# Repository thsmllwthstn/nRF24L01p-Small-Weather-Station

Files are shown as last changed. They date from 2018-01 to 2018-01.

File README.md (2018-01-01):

# Small Weather Station with nRF24L01+

For any nRF24L01+ project!

Vcc: 3.3V - 15V

### Description
Start a nRF24L01+ sensor network or expand your existing projects with this Small Weather Station!
This comes with easy to use example codes for Arduino and Raspberry Pi!

This station measures and sends:

 -Temperature
 
 -Humidity
 
 -Lightintensity

To achieve this the station uses three different sensors:

 -DS18B20: Digital temperature sensor
 
 -DHT11: Basic temperature and humidity sensor
 
 -LDR: Measures lightintensity

### What do you need?
You will need a Small Weather Station and your own nRF24L01+ receiver.
You can buy the Small Weather Station in the link below:

--ebay link

Or you can build your own station, you can find the schematics and source code in the link below:
https://github.com/thsmllwthstn/nRF24L01p-Small-Weather-Station/tree/master/station/station_basic

In the link below you will find an easy example code written for Arduino and Python 3 for receiving data from the station:
https://github.com/thsmllwthstn/nRF24L01p-Small-Weather-Station/tree/master/receiver

Simply copy and paste this code and you are ready to retreive data from the station!

### How does it work?
Power the Vin pin with 3V3 - 15V.

As soon as the onboard LED blinks 2 times in a row the station starts sending the data.

Use the example code to receive the data.

It sends the data every 5 seconds.

You can change the stations settings by pressing the button. The LED will go ON. The station is now in receiving mode.
There are 4 settings you can change:

 -Timer (rate at which the station sends the data in seconds)
 
 -Tranceive address
 
 -Receive address
 
 -Frequency

The example code explains in detail how to change these settings.

### Add a waterproof digital temperature sensor!
The station comes with 3 additional pins for connecting a waterproof DS18B20 temperature sensor.
Solder the Vcc, data and ground pins from the temperature sensor to the 3V3, data and GND pin from the station.
Once connected the station detects the presence of the added DS18B20 sensor.
The station will now send the standard readings with the added DS18B20 sensor!

### Programmable Small Weather Station?
Do you want full access to all the settings or use the station to control any other 3V3 circuit?
This is possible with a USBASP programmer and the programmable small weather station: 

--ebay link

Or you can build your own programmable station, you can find the schematics and source code in the link below:
https://github.com/thsmllwthstn/nRF24L01p-Small-Weather-Station/tree/master/station/station_basic_with_programmer

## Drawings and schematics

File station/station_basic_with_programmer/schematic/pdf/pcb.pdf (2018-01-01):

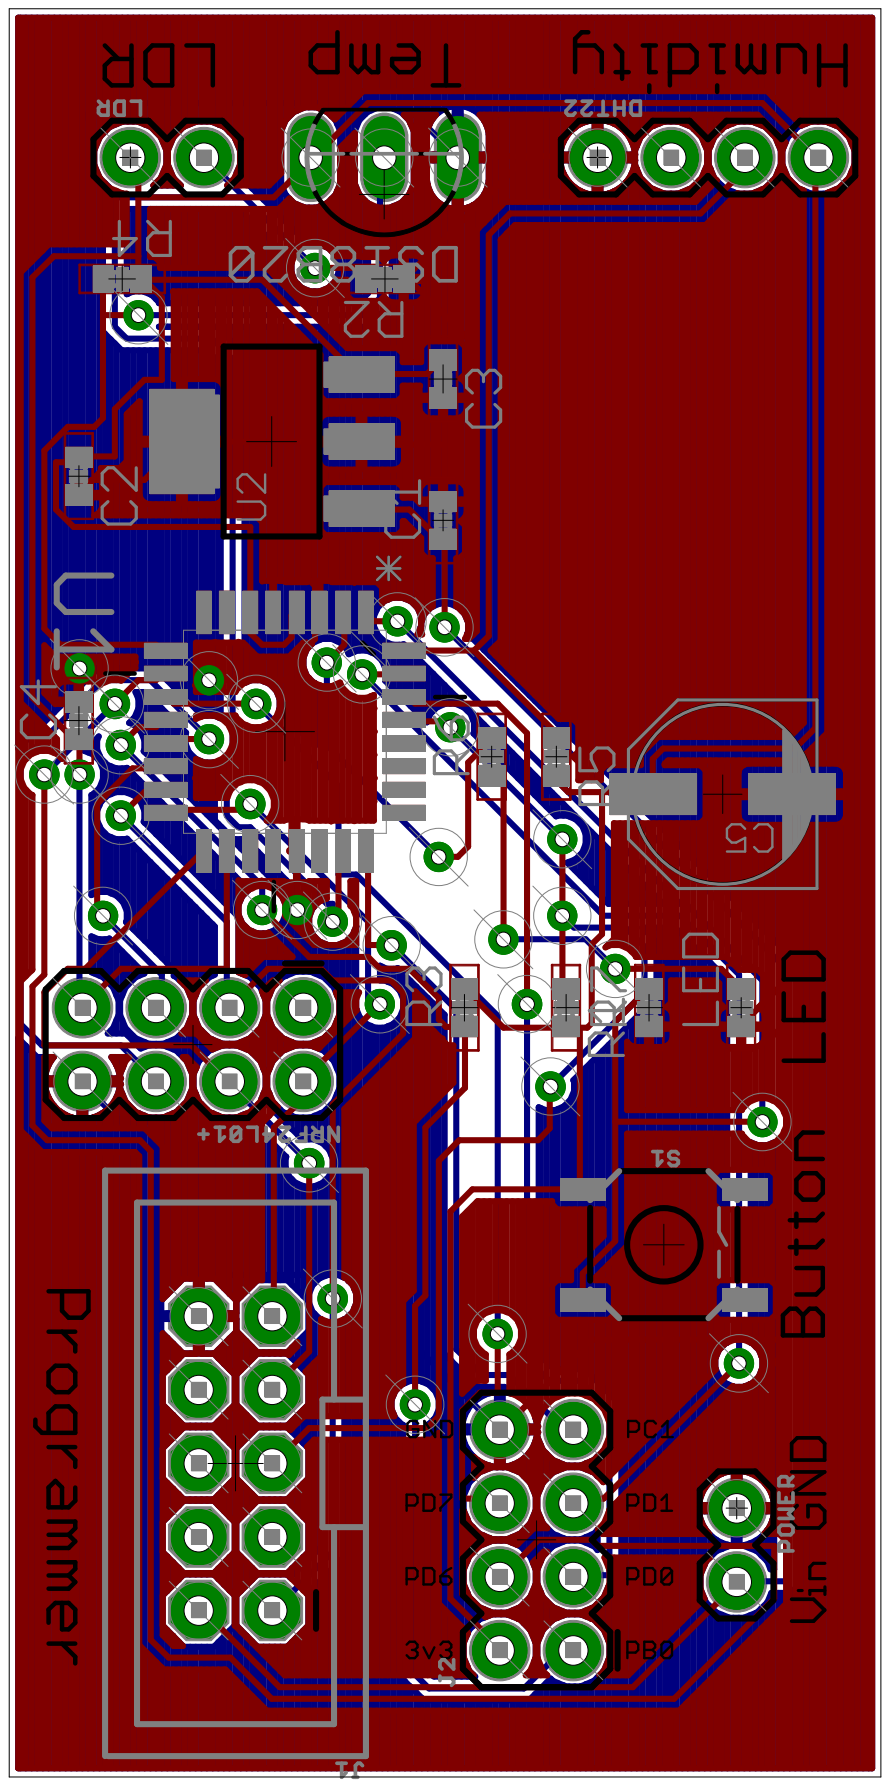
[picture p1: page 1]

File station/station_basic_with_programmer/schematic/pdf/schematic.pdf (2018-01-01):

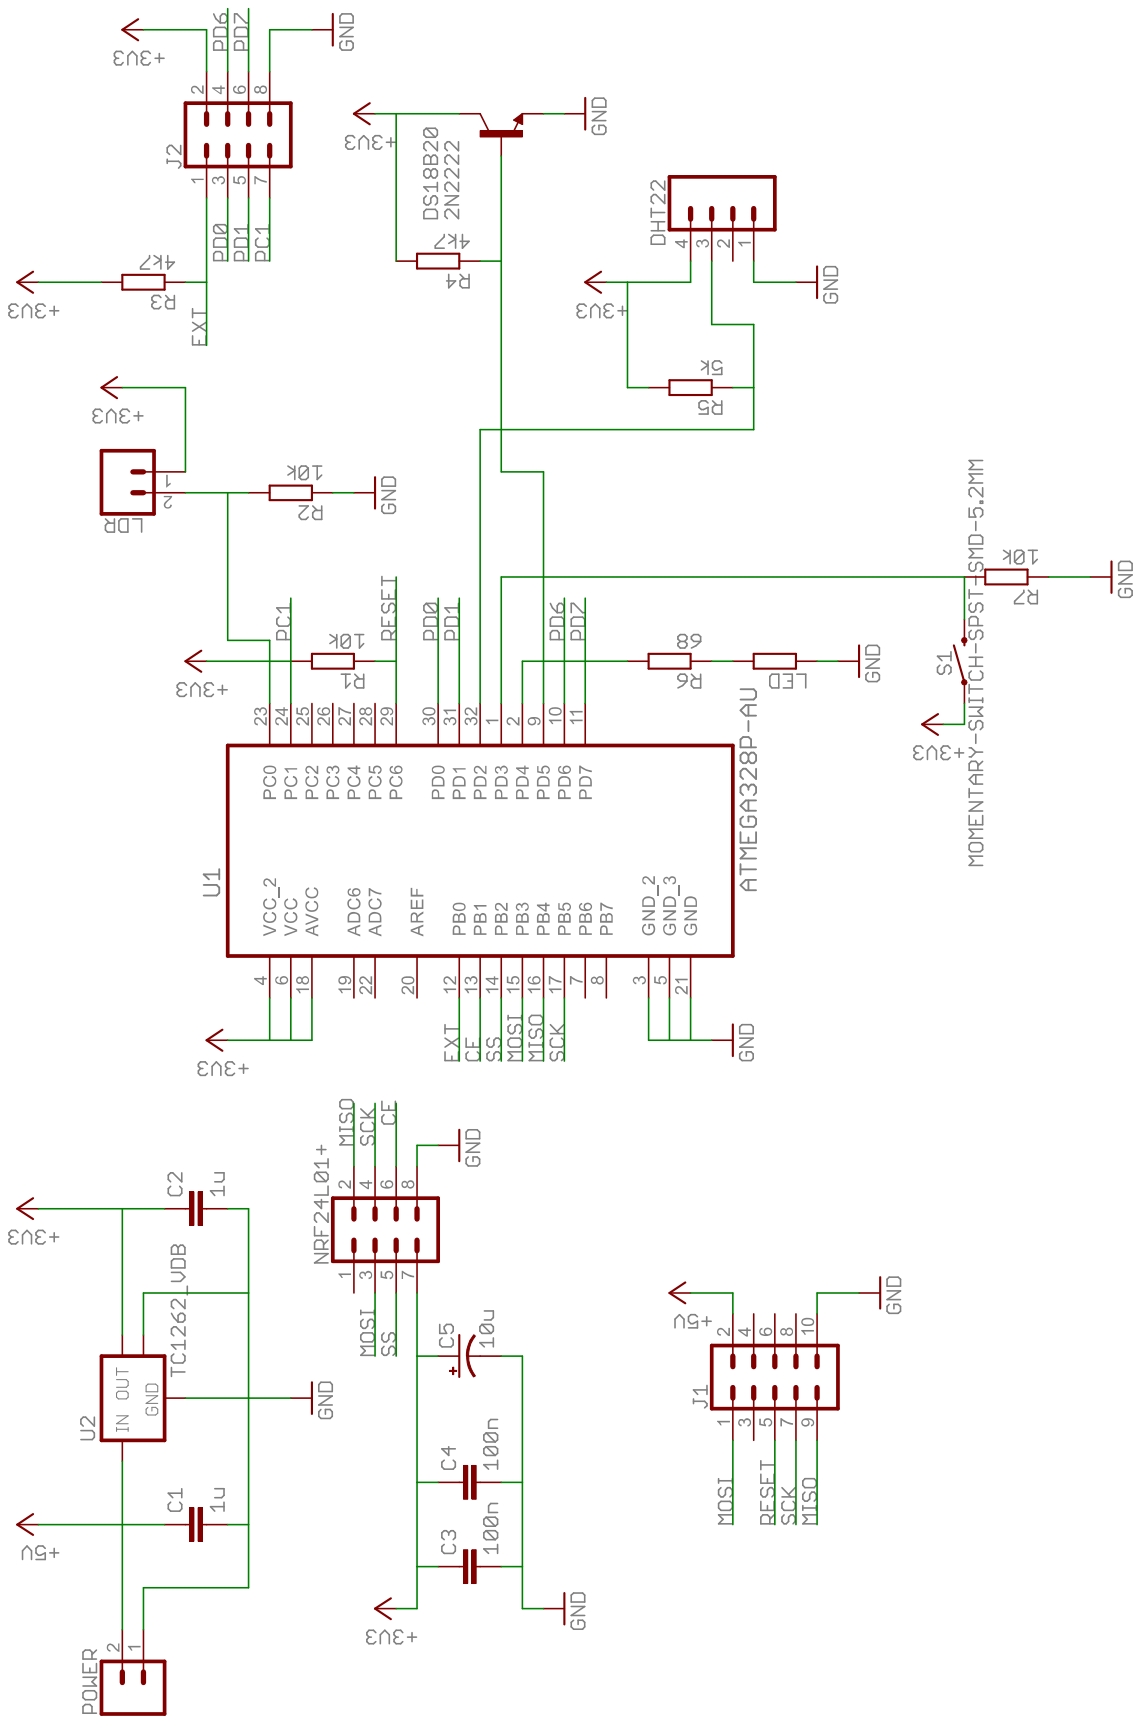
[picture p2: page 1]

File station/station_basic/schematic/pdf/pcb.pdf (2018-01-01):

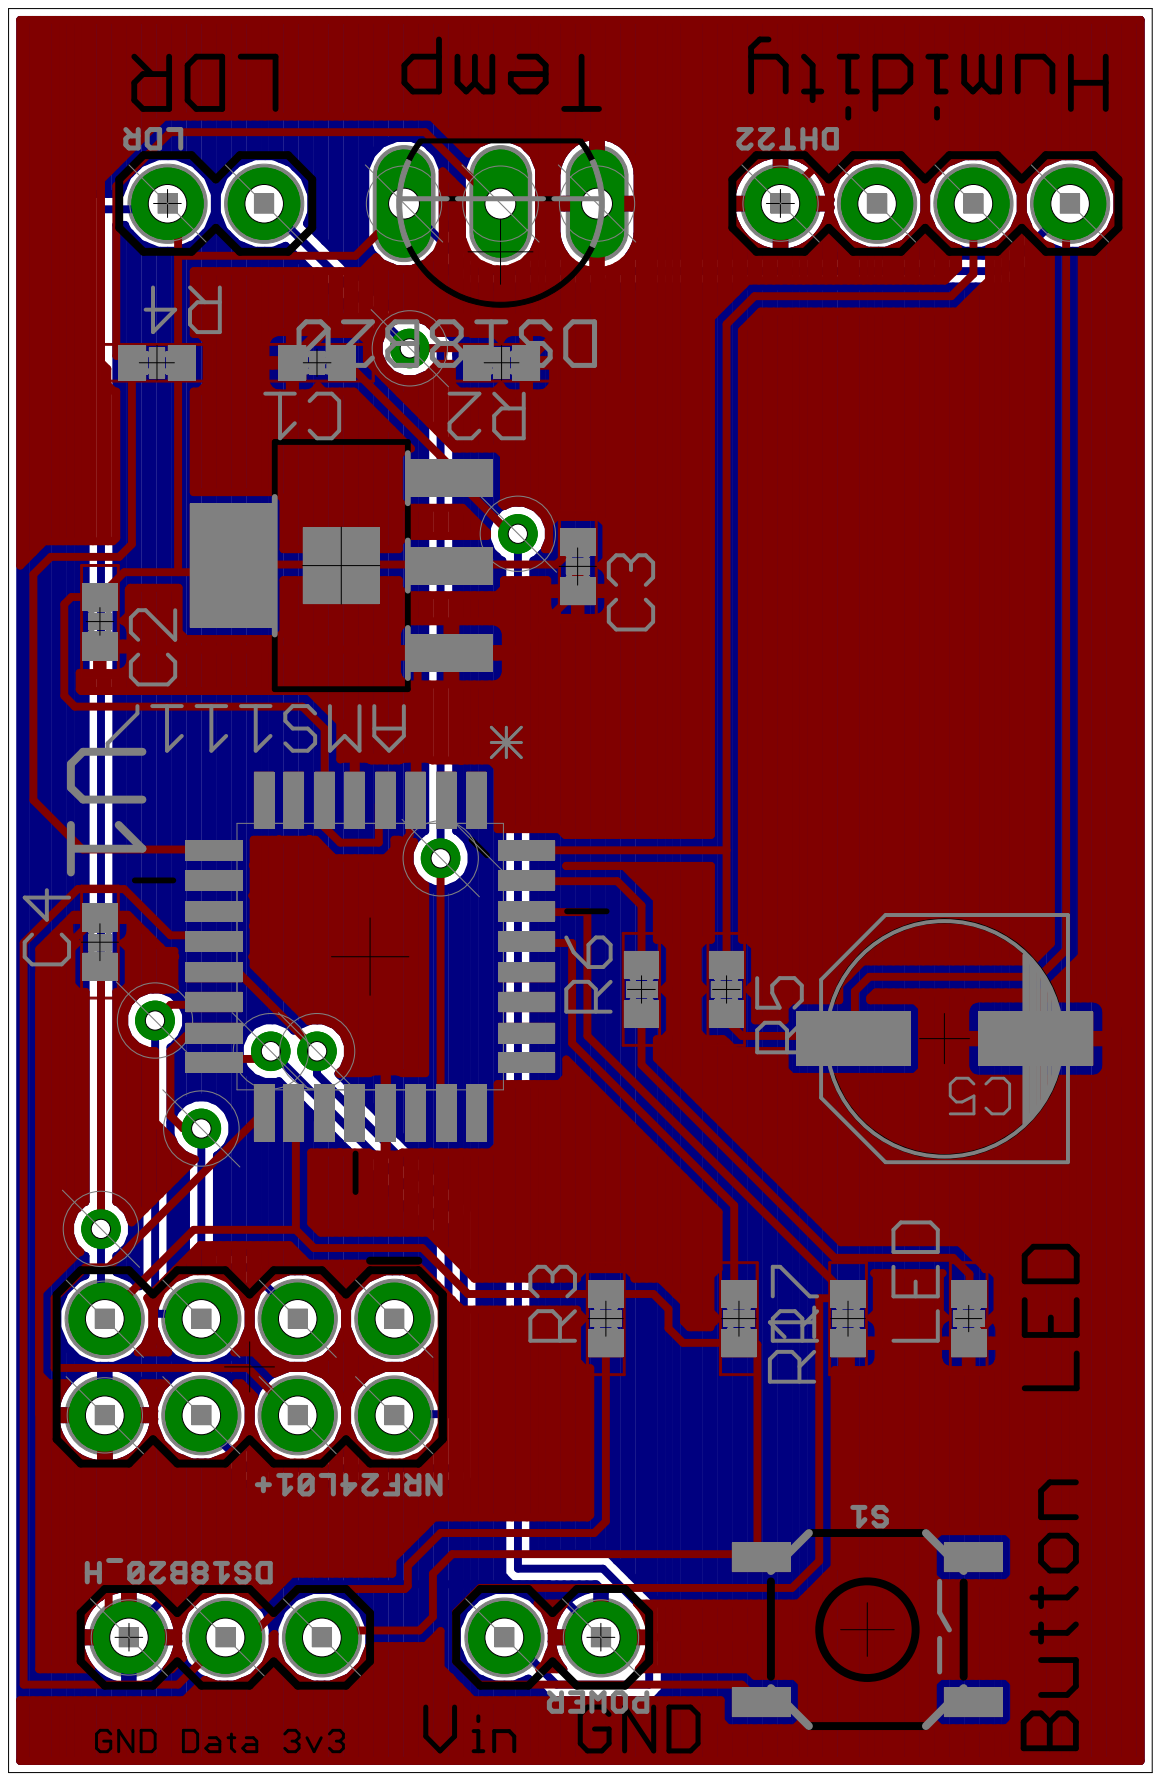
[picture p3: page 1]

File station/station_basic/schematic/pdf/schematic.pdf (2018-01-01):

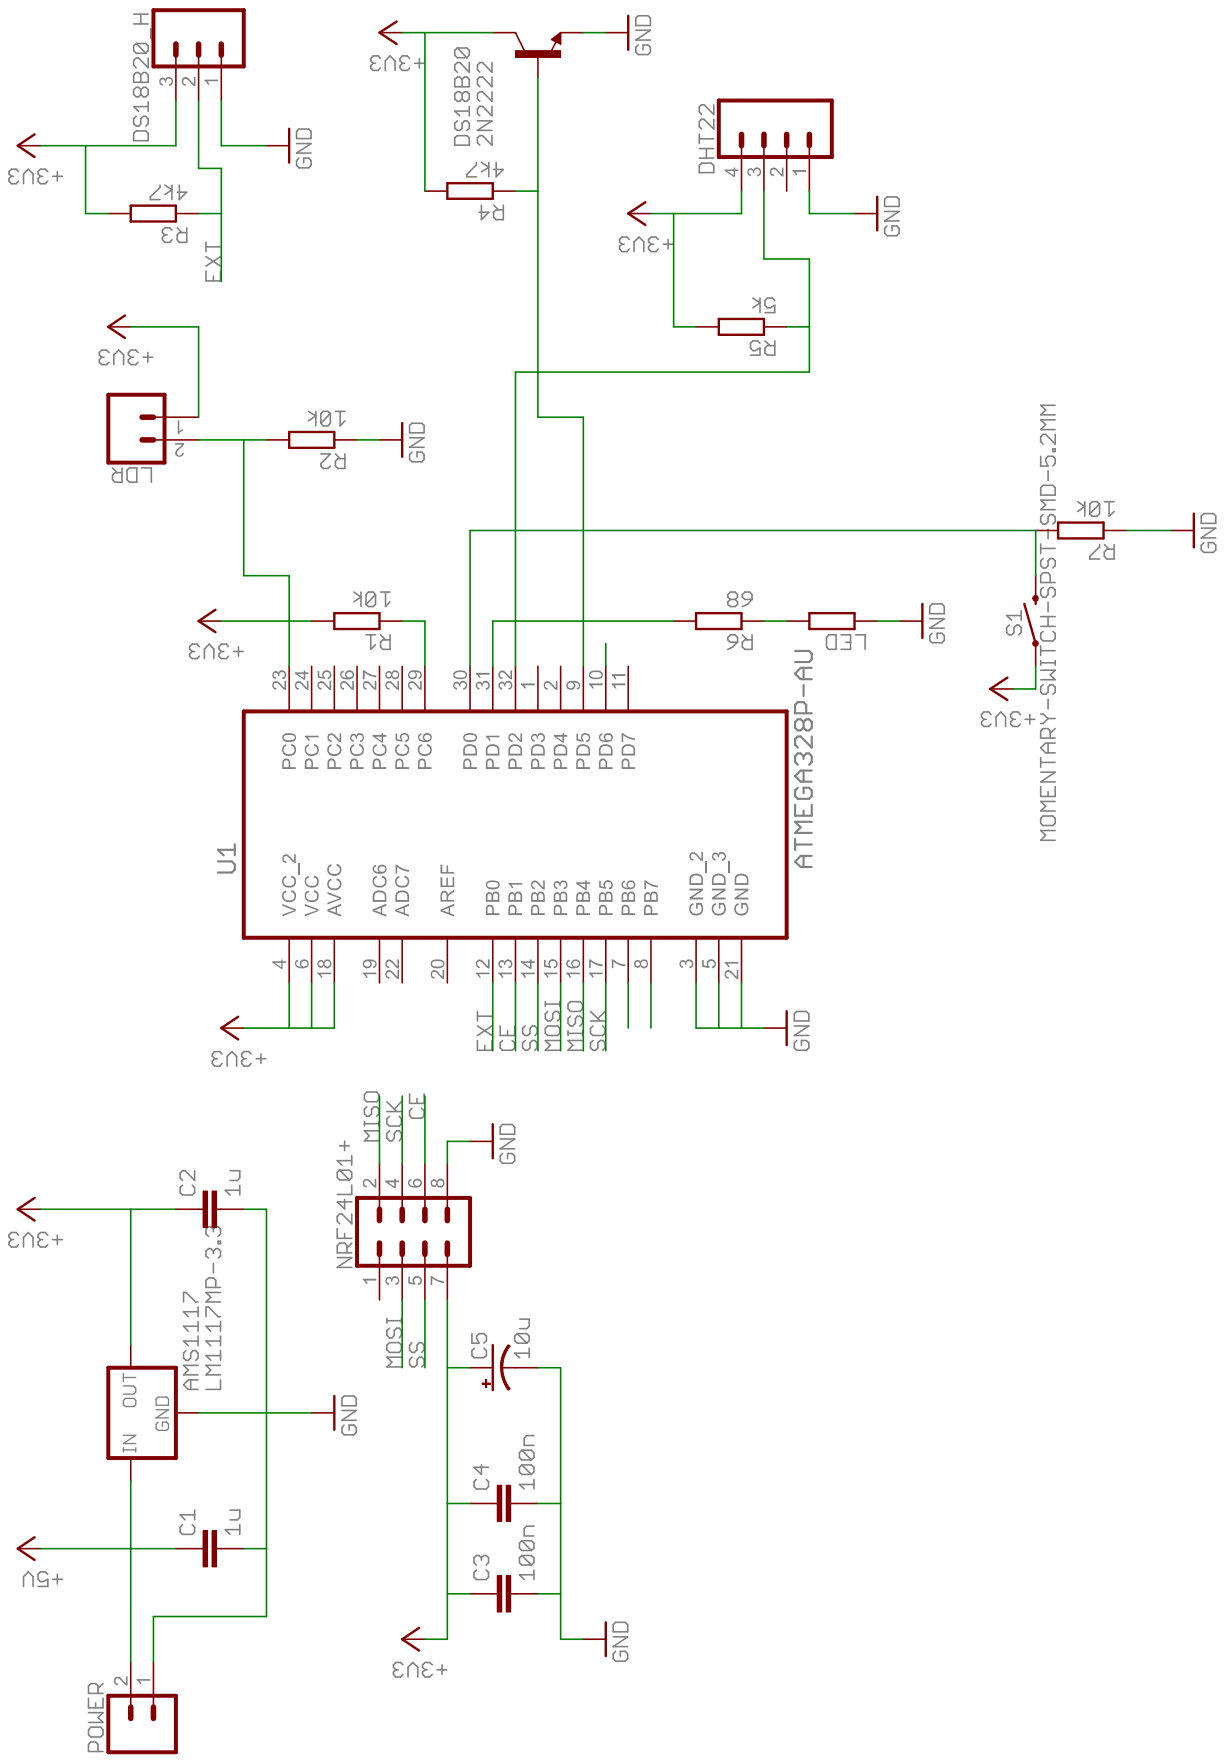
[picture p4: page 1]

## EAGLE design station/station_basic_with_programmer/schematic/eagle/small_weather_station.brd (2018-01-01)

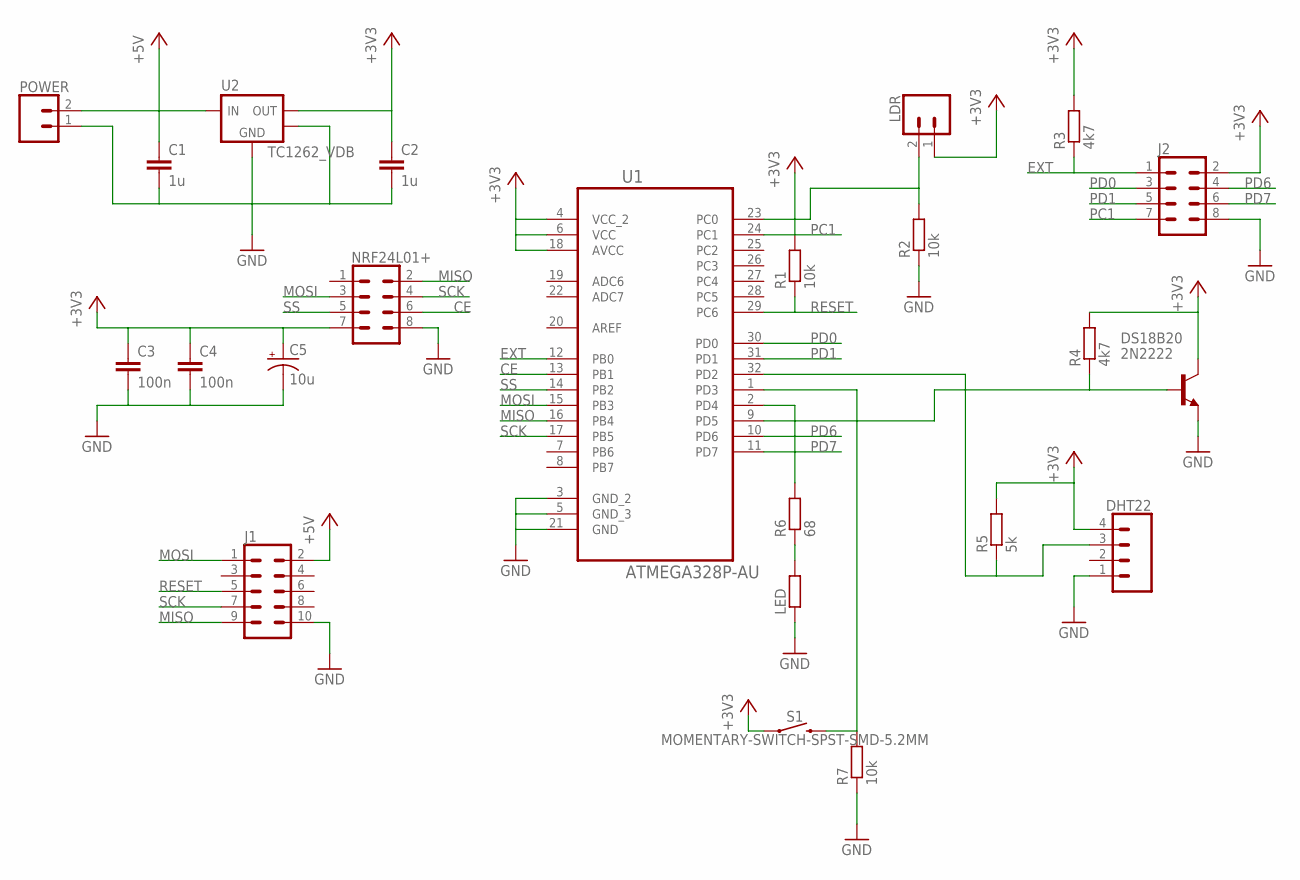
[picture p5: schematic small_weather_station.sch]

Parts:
C1, C2: 1u; C0402
C3, C4: 100n; C0402
C5: 10u; PANASONIC_D
DHT22: CONN_04; 1X04
DS18B20: 2N2222; TO92-EBC-OVAL
J1: CONN_05X2SHD-NS; 2X5-SHROUDED-NS
J2: CONN_04X2; 2X4
LDR: CONN_02; 1X02
LED: R-EU_R0402; R0402
NRF24L01+: CONN_04X2; 2X4
POWER: CONN_02; 1X02
R1, R2, R7: 10k; R0402
R3, R4: 4k7; R0402
R5: 5k; R0402
R6: 68; R0402
S1: MOMENTARY-SWITCH-SPST-SMD-5.2MM; TACTILE_SWITCH_SMD_5.2MM
U1: ATMEGA328P-AU; QFP80P900X900X120-32N
U2: TC1262_VDB; SOT-223-3

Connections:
+3V3: C2.1, C3.1, C4.1, C5.+, DHT22.4, DS18B20.C, J2.2, LDR.1, NRF24L01+.7, R1.2, R3.2, R4.2, R5.2, S1.1, U1.4 (VCC_2), U1.6 (VCC), U1.18 (AVCC), U2.3 (VOUT)
+5V: C1.1, J1.2, POWER.2, U2.1 (VIN)
CE: NRF24L01+.6, U1.13 (PB1)
EXT: J2.1, R3.1, U1.12 (PB0)
GND: C1.2, C2.2, C3.2, C4.2, C5.-, DHT22.1, DS18B20.E, J1.10, J2.8, LED.1, NRF24L01+.8, POWER.1, R2.1, R7.1, U1.3 (GND_2), U1.5 (GND_3), U1.21 (GND), U2.2 (GND), U2.4 (TAB)
MISO: J1.9, NRF24L01+.2, U1.16 (PB4)
MOSI: J1.1, NRF24L01+.3, U1.15 (PB3)
unnamed: R6.2, U1.2 (PD4)
unnamed: DHT22.3, R5.1, U1.32 (PD2)
unnamed: LDR.2, R2.2, U1.23 (PC0)
unnamed: DS18B20.B, R4.1, U1.9 (PD5)
unnamed: LED.2, R6.1
unnamed: R7.2, S1.3 (2), U1.1 (PD3)
PC1: J2.7, U1.24 (PC1)
PD0: J2.3, U1.30 (PD0)
PD1: J2.5, U1.31 (PD1)
PD6: J2.4, U1.10 (PD6)
PD7: J2.6, U1.11 (PD7)
RESET: J1.5, R1.1, U1.29 (PC6)
SCK: J1.7, NRF24L01+.4, U1.17 (PB5)
SS: NRF24L01+.5, U1.14 (PB2)

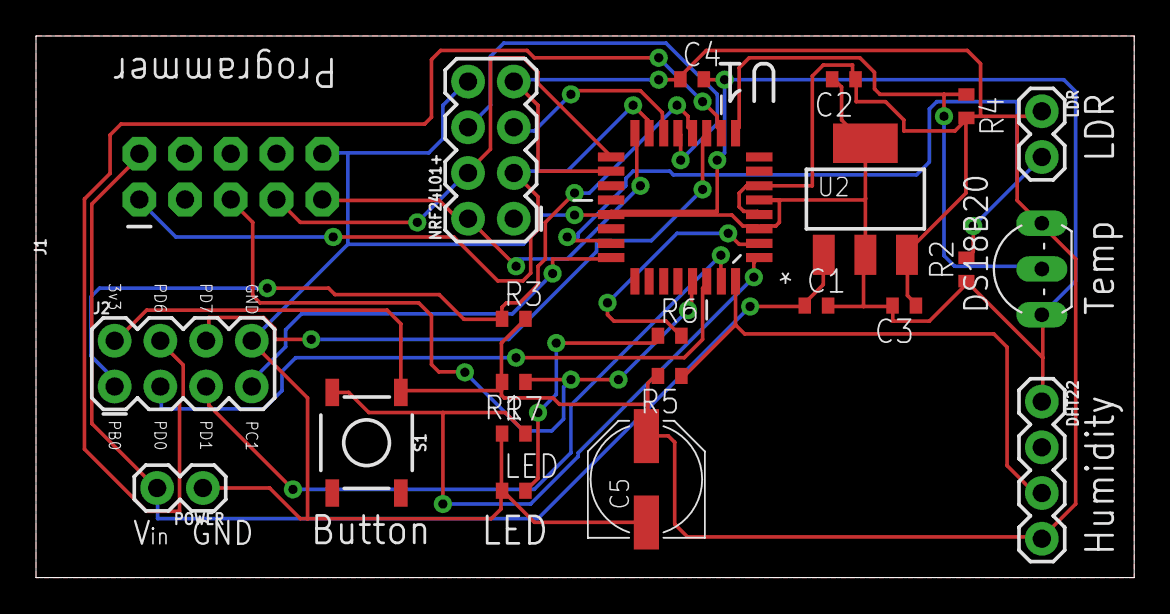
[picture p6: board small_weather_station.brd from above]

Board: 2 copper layers, 61.0 x 30.1 mm, 23 parts (0 on the bottom side), 21 nets.

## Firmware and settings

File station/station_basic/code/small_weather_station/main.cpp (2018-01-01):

/*
 * Code for Small Weather Station
 */

#define F_CPU 1000000

#include <avr/io.h>
#include <util/delay.h>
#include <stdlib.h>
#include <avr/interrupt.h>
#include "nrf24l01p.h"
#include "dht.h"
#include "adc.h"
#include "ds18b20.h"

#define LED      PIND3
#define BUTTON   PIND5
#define RX_MODE  0x00
#define TX_MODE  0x01

#define TEMPERATURE_PIN     PIND4
#define EXT_TEMPERATURE_PIN PIND0

//Prototypes
void send_tx_data(void);

//Make objects from classes
nRF24L01P my_nrf;
adc       my_adc;
dht       my_humidity;

//Variables 
uint8_t TRANSFER_SIZE;
uint8_t TX_DATA[10];
uint8_t RX_DATA[10];
uint16_t one_second_counter = 0;
uint16_t *one_second_counter_ptr;
uint16_t send_tx_timer = 5;
bool debounce = false;
bool rx_error = false;
bool send_response = false;
int mode = TX_MODE;

int main(void)
{
	/******* Check if the external temperature sensor is connected or not *******/
	uint8_t dummy_array[2];
	(getTemperature(dummy_array, EXT_TEMPERATURE_PIN) ) ? TRANSFER_SIZE = 10 : TRANSFER_SIZE = 8;	
	
	my_humidity.initDHT();
	my_adc.initADC();
	
	/******* nRF24L01+ Settings *******/
	my_nrf.setOutputPower(OUTPUT_POWER_MINUS_18DBM);
	my_nrf.setAirDataRate(AIR_DATA_RATE_250KBPS);
	my_nrf.setCyclicRedundancyCheck(CYCLIC_REDUNDANCY_CHECK_1BYTE);
	my_nrf.disableAutoAcknowledgment();
	my_nrf.disableAutoRetransmit();
	my_nrf.enableDataPipe(DATA_PIPE_ALL);
	my_nrf.setTransferSize(DATA_PIPE_0, TRANSFER_SIZE);
	my_nrf.setTransferSize(DATA_PIPE_1, TRANSFER_SIZE);
	my_nrf.setTransferSize(DATA_PIPE_2, TRANSFER_SIZE);
	my_nrf.setTransferSize(DATA_PIPE_3, TRANSFER_SIZE);
	my_nrf.setTransferSize(DATA_PIPE_4, TRANSFER_SIZE);
	my_nrf.setTransferSize(DATA_PIPE_5, TRANSFER_SIZE);

	my_nrf.setReceiveMode();

	/* Enable Clear Timer on Compare mode */
	TCCR1B |= (1 << WGM12);

	/* Enable timer interrupt */
	TIMSK1 |= (1 << OCIE1A);

	/* One Second Calculation
	 * time[s] = frequency / (prescaler * compare) 
	 * 1000000 / (64 * (15625 - 1)) = 1[s]   */
	TCCR1B |= (1 << CS11) | (1 << CS10);
	OCR1A = 0x3D08;

	/* Enable interrupts */
	sei();

	//Set the LED as output
	DDRD |= 1<<LED;

	//Set the button as input
	DDRD &= ~(1<<BUTTON);	

	//Toggle the led to let the user know the PCB is ready to use...
	for(int i = 0; i < 4; i++)
	{
		PORTD ^= 1<<LED;
		_delay_ms(250);
	}

	send_tx_data();

    while(1)
    {
		one_second_counter_ptr = &one_second_counter;
		if(*one_second_counter_ptr >= send_tx_timer && mode == TX_MODE)
		{
			send_tx_data();
			one_second_counter = 0;
		}

		/* If button is pressed, toggle between RX en TX mode */
		if((PIND & 1<<BUTTON) && !debounce)
		{
			debounce = true;
			one_second_counter = 0;
			_delay_ms(5);
		}
		else if(!(PIND & 1<<BUTTON) && debounce && mode == TX_MODE)
		{
			my_nrf.setReceiveMode();
			PORTD |= 1<<LED;
			mode = RX_MODE;
			debounce = false;
			_delay_ms(5);
		}
		else if(!(PIND & 1<<BUTTON) && debounce && mode == RX_MODE)
		{
			my_nrf.setTransmitMode();
			PORTD &= ~(1<<LED);
			mode = TX_MODE;
			debounce = false;
			_delay_ms(5);
		}

		/* When the button is held down for 4 seconds, reset to standard configuration */
		else if( (PIND & 1<<BUTTON) && debounce)
		{
			if(*one_second_counter_ptr >= 4)
			{
				my_nrf.setFrequencyChannel(MINIMUM_FREQUENCY_CHANNEL + 2);
				my_nrf.setRXAddress(DATA_PIPE_0, 0xE7E7E7E7E7);
				my_nrf.setRXAddress(DATA_PIPE_1, 0xC2C2C2C2C2);
				my_nrf.setRXAddress(DATA_PIPE_2, 0xC3);
				my_nrf.setRXAddress(DATA_PIPE_3, 0xC4);
				my_nrf.setRXAddress(DATA_PIPE_4, 0xC5);
				my_nrf.setRXAddress(DATA_PIPE_5, 0xC6);
				my_nrf.setTXAddress(0xE7E7E7E7E7);
				send_tx_timer = 5;

				for(int i = 0; i < 8; i++)
				{
					PORTD ^= 1<<LED;
					_delay_ms(250);
				}
				debounce = false;
				_delay_ms(5);
			}
		}

		/* When in RX mode, listen for incomming data */
		if(my_nrf.readable() && mode == RX_MODE)
		{
			int rx_length = my_nrf.readData(RX_DATA, sizeof(RX_DATA));

			//Check if the user wants to set the timer
			if(RX_DATA[0] == 't' && RX_DATA[1] == '=')
			{
				//Read the data until 's'
				char new_time[TRANSFER_SIZE];
				for(int i = 0; i < rx_length; i++)
				{
					char c = RX_DATA[i + 2];

					if(c == 's')
					{
						if(i == 1) send_tx_timer = RX_DATA[i + 1] - '0';
						else send_tx_timer = atoi(new_time);
						send_response = true;
						break;
					}
					else
					{
						//Check if the received data is valid...
						if (c >= '0' && c <= '9') new_time[i] = RX_DATA[i + 2];
						else
						{
							rx_error = true;
							break;
						}
					}
				}
				if(send_tx_timer < 2 || send_tx_timer > 65535) rx_error = true;
			}

			//Check if the user wants to change the TX-address
			else if(RX_DATA[0] == 't' && RX_DATA[1] == 'a' && RX_DATA[2] == '=')
			{
				uint8_t tx_address[5];

				//LSByte first
				for(int i = 0; i < 5; i++)
				{
					tx_address[4 - i] = RX_DATA[i + 3];
				}
				my_nrf.setTXAddress(tx_address);
			}
      
			//Check if the user wants to change the RX-address
			else if(RX_DATA[0] == 'r' && RX_DATA[2] == '=')
			{
				uint8_t pipe = RX_DATA[1] - '0';

				if(pipe == 0 || pipe == 1)
				{
					uint8_t rx_address[5];

					//LSByte first
					for(int i = 0; i < 5; i++)
					{
						rx_address[4 - i] = RX_DATA[i + 3];
					}
					my_nrf.setRXAddress(pipe, rx_address);
					send_response = true;
				}

				  else if(pipe >= 2 && pipe <= 5)
				  {
					  my_nrf.setRXAddress(pipe, RX_DATA[3]);
					  send_response = true;
				  }

				else
				{
					rx_error = true;
				}
			}
			      
		    //Check if the user wants to change the frequency
			else if(RX_DATA[0] == 'f' && RX_DATA[1] == 'r' && RX_DATA[2] == 'e' && RX_DATA[3] == '=' )
			{
				char new_frequency[4];

				for(uint8_t i = 0; i < sizeof(new_frequency); i++)
				{
					char c = RX_DATA[i + 4];

					if(c >= '0' && c <= '9') new_frequency[i] = c;
					else
					{
						rx_error = true;
						break;
					}
				}

				uint16_t f = atoi(new_frequency);

				if(f >= MINIMUM_FREQUENCY_CHANNEL && f <= MAXIMUM_FREQUENCY_CHANNEL)
				{
					my_nrf.setFrequencyChannel(f);
				}
				else rx_error = true;
			}
					
			else
			{
				rx_error = true;
			}
			my_nrf.setTransmitMode();
	    
			/* Let the user know an error occured, stay in receive mode after */
			if(rx_error)
			{
				uint8_t ERROR_DATA[10] = {'-', 'e', 'r', 'r', 'o', 'r', '!', '-', '-', '-'};
				my_nrf.writeData(ERROR_DATA, TRANSFER_SIZE);
				mode = RX_MODE;
				rx_error = false;
			}
	    
			/* If no error occured, let the user know by echoing the data back
			 * Also, send the data and go in sleep mode after */
			else
			{
				if(send_response)
				{
					my_nrf.writeData(RX_DATA, TRANSFER_SIZE);
					send_tx_data();
					send_response = false;
				}
				one_second_counter = 0;
				mode = TX_MODE;
				PORTD &= ~(1<<LED);
			}
		}
    }		
}

void send_tx_data(void)
{
	//Variables
	uint8_t data_counter = 0, new_data_counter = 0;

	/**************************** Temperature Sensor ****************************/
	//Read the temperature and store the bytes
	uint8_t temperature_data[2];
	if(getTemperature(temperature_data, TEMPERATURE_PIN) )
	{
		//Add the bytes to the array we're going to send
		for(uint8_t i = 0; i < sizeof(temperature_data); i++)
		{
			TX_DATA[i + data_counter] = temperature_data[i];
			new_data_counter++;
		}
	}
	data_counter = new_data_counter;

	/***************************** Humidity Sensor ******************************/	
	//Read the DHT11 data and store the bytes
	uint8_t DHT_data[4];
		
	my_humidity.request();
	
	if(my_humidity.response() )
	{	
		for(int i = 0; i < 4; i++)
		{
			uint8_t dht_byte = my_humidity.read_bytes();
		
			if(dht_byte != -1)
			{
				DHT_data[i] = dht_byte;
			}
		}

		uint8_t DHT_checksum  = my_humidity.read_bytes();
	
		if ((DHT_data[0] + DHT_data[1] + DHT_data[2] + DHT_data[3]) == DHT_checksum)
		{
			//Add the bytes to the array we're going to send
			for(uint8_t i = 0; i < sizeof(DHT_data); i++)
			{
				TX_DATA[i + data_counter] = DHT_data[i];
				new_data_counter++;
			}
		}	
	}
	data_counter = new_data_counter;

	/******************************* Analog Value *******************************/
	//Read the analog value and store the bytes
	uint8_t analogValue[2];

	if(my_adc.analogRead(analogValue) )
	{
		//Add the bytes to the array we're going to send
		for(int i = 0; i < 2; i++)
		{
			TX_DATA[i + data_counter] = analogValue[i];
			new_data_counter++;
		}
	}
	data_counter = new_data_counter;

	/********************** External Temperature Sensor *************************/
	if(TRANSFER_SIZE == 10)
	{
		//Read the temperature and store the bytes
		uint8_t ext_temperature_data[2];
		if(getTemperature(ext_temperature_data, EXT_TEMPERATURE_PIN) )
		{
			//Add the bytes to the array we're going to send
			for(uint8_t i = 0; i < sizeof(ext_temperature_data); i++)
			{
				TX_DATA[i + data_counter] = ext_temperature_data[i];
				new_data_counter++;
			}
		}
		data_counter = new_data_counter;
	}
	
	//Send to array to the nRF24L01+
	my_nrf.writeData(TX_DATA, TRANSFER_SIZE);

	//Put the nRF24L01+ in sleep mode
	my_nrf.powerDown();
}

ISR (TIMER1_COMPA_vect)
{
	one_second_counter++;
}

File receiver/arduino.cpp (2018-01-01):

/* 
 * Small Weather Station
 * https://github.com/thsmllwthstn/nRF24L01p-Small-Weather-Station
 * 
 * Simply power the Small Weather Station with 3V3 - 12V and it begins
 * sending data.
 * 
 * To change settings press the button and the LED should turn ON.
 * The station is now in receiving mode.
 * 
 * Type the following commands in the serial monitor to change the settings:
 * |----------------------------------------------|
 * |      COMMAND                  EXAMPLE STRING |
 * |----------------------------------------------|
 * |t=[time in seconds]s         | t=100s         | --> sets timer to 100 seconds
 * |ta=[tx address]              | ta=AAAAB       | --> sets transmit address to 0x4141414142*
 * |r[pipe number]=[rx address]  | r0=JJJJK       | --> sets receive address of pipe 0 to 0x4A4A4A4A4B*
 * |fre=[frequency]              | fre=2450       | --> sets frequency to 2450MHz**
 * |----------------------------------------------|
 * 
 * Note*: don't forget to change the addresses of this program also!
 * Note**: don't forget to change the frequency of this program also!
 * 
 * The settings are safed even when resetting (power down) the station.
 * 
 * To reset the settings to default configuration hold the button down 
 * until the LED begings toggeling.
 * 
 */

#include <SPI.h>
#include "nRF24L01.h"
#include "RF24.h"
#include "printf.h" 

//When you connect an external DS18B20 temperature sensor to
//the PCB, change the transfer size to 10
#define TRANSFER_SIZE 8
//#define TRANSFER_SIZE 10

#define DATA_PIPE_0 0
#define DATA_PIPE_1 1
#define DATA_PIPE_2 2
#define DATA_PIPE_3 3
#define DATA_PIPE_4 4
#define DATA_PIPE_5 5
#define tx_address 0xE7E7E7E7E7
#define rx_address 0xE7E7E7E7E7

RF24 my_nrf(9,10);

uint8_t rx_data[TRANSFER_SIZE];
char tx_data[TRANSFER_SIZE];

void setup(void)
{
  Serial.begin(115200);
  printf_begin();

  //Standard nRF24L01+ Settings for communication with the Small Weather Station
  //Don't forget to change these when changing the settings of the station!
  my_nrf.begin();
  my_nrf.setPALevel(RF24_PA_MIN);
  my_nrf.setDataRate(RF24_250KBPS);
  my_nrf.setCRCLength(RF24_CRC_8);
  my_nrf.setPayloadSize(TRANSFER_SIZE);
  my_nrf.setChannel(2);
  my_nrf.setAutoAck(false);
  my_nrf.openReadingPipe(DATA_PIPE_0, rx_address);
  my_nrf.openWritingPipe(tx_address);
  my_nrf.startListening();
 
  //Print the nRF24L01+ settings
  my_nrf.printDetails();
  Serial.print("Transfer size    = ");
  Serial.print(TRANSFER_SIZE);
  Serial.println(" bytes\n");
   
  Serial.println("*********** NOW LISTENING FOR REQUESTS FROM THE SMALL WEATHER STATION ***********");
}
void loop(void)
{
  if(my_nrf.available() ) 
  {
    my_nrf.read(rx_data, sizeof(rx_data));

    //Check if the received data is an error indicator, change of settings or
    //represents values from the sensors
    if(rx_data[0] == 't' && rx_data[1] == '=')
    {
      Serial.print("\nReceived data back from the Small Weather Station!\nThe timer is set to: ");

      for(int i = 2; i < sizeof(rx_data); i++)
      {     
        char c = rx_data[i];
        if(c == 's')
        {
          break;
        }
        else
        {
          Serial.print(c);
        }
      }
      Serial.println(" seconds\n");
    }
    else if(rx_data[0] == 'r' && rx_data[2] == '=')
    {
      Serial.print("\nReceived data back from the Small Weather Station!\nThe receive address of pipe ");
      
      uint8_t pipe = rx_data[1] - '0';
      
      Serial.print(pipe);
      
      Serial.print(" is set to: 0x");
      
      if(pipe <= 2)
      {
        for(int i = 3; i < sizeof(rx_data); i++)
        {
          Serial.print(rx_data[i], HEX);
        }
      }
      else 
      {
        Serial.print(rx_data[3], HEX);
      }
      Serial.println();
    }
    else if(rx_data[1] == 'e' && rx_data[2] == 'r' && rx_data[3] == 'r' && rx_data[4] == 'o' && rx_data[5] == 'r') 
    {
      Serial.print("\nReceived data back from the Small Weather Station!\nReceived message: ");
      
      for(int i = 0; i < sizeof(rx_data); i++) 
      {
        Serial.print((char)rx_data[i]);
      }
    }

    //************ Print and calculate the data values from the Small Weather Station ************//
    else
    {
        //*** Print the raw data ***//
        for(int i = 0; i < sizeof(rx_data); i++)
        {
          Serial.print(rx_data[i]);
          Serial.print(' ');
        }
        
      //****************** Calculate the temperature from the DS18B20 ******************//
        //The most precise 12-bit resolution is used    
        const float RESOLUTION = 0.0625;
          
        uint16_t raw_temperature = (rx_data[1] << 8) + rx_data[0];
        
        float Celcius = (float) raw_temperature * RESOLUTION;
        
        Serial.print("\nDS18B20 Temperature : ");
        Serial.println(Celcius);
        
    
      //************* Calculate the humidity and temperature from the DHT11 ************//
        float dht_humidity = rx_data[2] + (rx_data[3] * 0.01);
    
        float dht_temperature = rx_data[4] + (rx_data[5] * 0.01);
    
        Serial.print("DHT11 Humidity      : ");
        Serial.println(dht_humidity);
        Serial.print("DHT11 Temperature   : ");
        Serial.println(dht_temperature);
        
    
      //******************** Calculate the value from the 10-bit ADC ********************//    
        //Since a 10-bit ADC is used, the highest value is 1023
        uint16_t analogValue = (rx_data[7] << 8) + rx_data[6];
    
        Serial.print("Analog value        : ");
        Serial.println(analogValue);
      
      // When connected, calculate the temperature from the externally connected DS18B20 //
        if(TRANSFER_SIZE == 10)
        {
          uint16_t raw_external_temperature = (rx_data[9] << 8) + rx_data[8];
          
          Celcius = (float) raw_external_temperature * RESOLUTION;
          
          Serial.print("Waterproof DS18B20  : ");
          Serial.println(Celcius);
        }
        Serial.println();
      }
  }

  //Send the user input to the Small Weather Station
  //Make sure the Small Weather Station is in receiving mode! (onboard led is ON)
  if(Serial.available() )
  {
    String s = Serial.readString();
    
    my_nrf.stopListening();
    
    //Add the user input to the buffer
    for(int i = 0; i < sizeof(tx_data); i++)
    {
      tx_data[i] = s[i];
    }

    if(s.length() < sizeof(tx_data) )
    {
      //Add padding to make the data 8 or 10 bytes
      for(int i = s.length(); i < sizeof(tx_data); i++) 
      {
        tx_data[i] = '0';
      }
    }
    
    if(!my_nrf.write(tx_data, sizeof(tx_data)) ) 
    {
      Serial.println("Something went wrong, try again!");
    }
    else
    {
      Serial.print("Sended: '");
      for(int i = 0; i < sizeof(tx_data); i++)
      {
        Serial.print(tx_data[i]);
      }
      Serial.println("' to the Small Weather Station\nWaiting for response...");
    }
    my_nrf.startListening(); 
  }
}

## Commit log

2018-01-01 arduino
    tested on arduino uno
2018-01-01 python
    tested on raspberry pi 3 mobel B
2018-01-01 python 3
    tested on raspberry pi 3 model b

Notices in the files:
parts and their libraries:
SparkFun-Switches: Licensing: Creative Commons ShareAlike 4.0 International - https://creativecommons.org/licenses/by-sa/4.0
